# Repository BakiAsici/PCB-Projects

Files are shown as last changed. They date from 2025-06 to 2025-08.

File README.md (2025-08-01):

<h2>ESP32-S3-WROOM-1 V1.1 — Custom PCB - Baki Asici</h2>

<p>
  <strong>Updated from V1.0 with improved routing, GPIO reassignment, and antenna layout adjustments.</strong>
</p>

<p>
  A custom-designed ESP32-S3 board featuring onboard I²C sensors, GPIO breakout headers, and full custom routing.  
  Designed in KiCad 9, fabricated by JLCPCB, and hand-assembled using hot air, hotplate, and soldering iron.
</p>

<h3>Overview</h3>

<ul>
  <li>Revision: Rev 1.1</li>
  <li>Designed in: KiCad 9</li>
  <li>Fabricated by: JLCPCB</li>
  <li>Assembly: Hand soldered (Hotplate, Hot Air, Soldering Iron)</li>
</ul>

<h3>Features</h3>

<ul>
  <li>ESP32-S3-WROOM-1 Module</li>
  <li>I²C-connected STMicroelectronics LIS2MDL magnetometer and Bosch Sensortec BME280 environmental sensor (Temperature, Humidity, Pressure)</li>
  <li>GPIO header breakout</li>
  <li>USB Programming and Monitoring</li>
  <li>WiFi and Bluetooth Capabilities</li>
</ul>

<h3>Noted Improvements from Rev 1.0</h3>
<ul>
  <li>Removed top mounting points to improve WiFi and Bluetooth performance, as recommended by the ESP32-S3-WROOM-1 datasheet</li>
  <li>Test LED (marked D1) was originally wired to a strapping pin (GPIO45), which caused unpredictable behaviour. It has now been rewired to a different GPIO</li>
  <li>Completed Custom Bosch BME280 I2C driver in the esp-idf framework. Reading from registers and applying Boch's calibration code</li>
  <li>Improved overall routing</li>
  <li>Followed ESP32-S3-WROOM-1 datasheet more closely regarding antenna clearance and placement</li>
</ul>
<p>It should be noted that IO numbering on back side of pcb may not fully correspond to what the actual pins are. Check schematic.</p>
<h3>Images</h3>
<div>
PCB 3D Renders
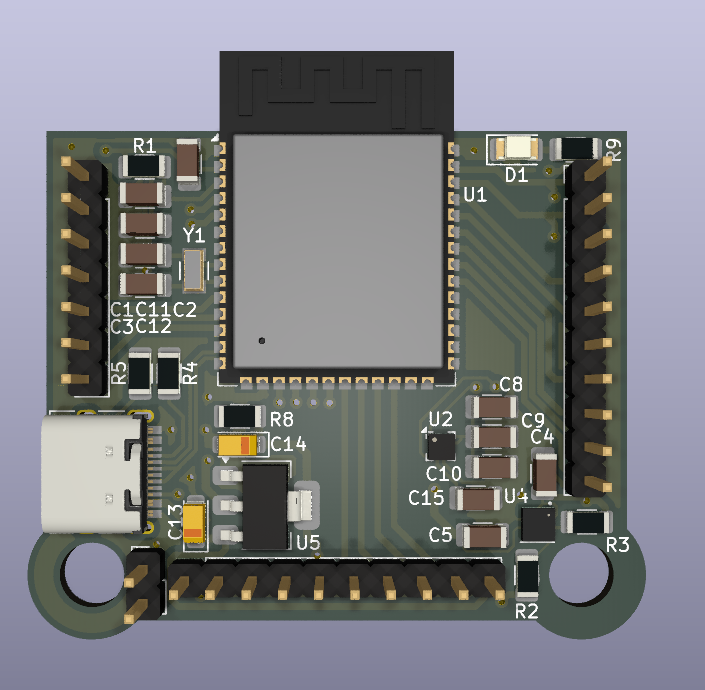
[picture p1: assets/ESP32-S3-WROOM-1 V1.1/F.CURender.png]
Front Render

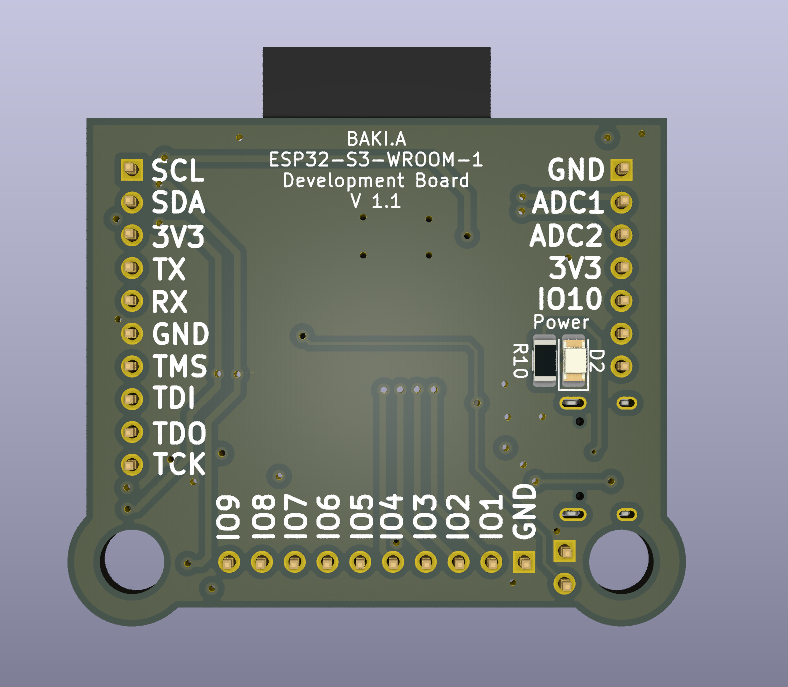
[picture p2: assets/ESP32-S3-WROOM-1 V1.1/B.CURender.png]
Back Render


PCB Photos
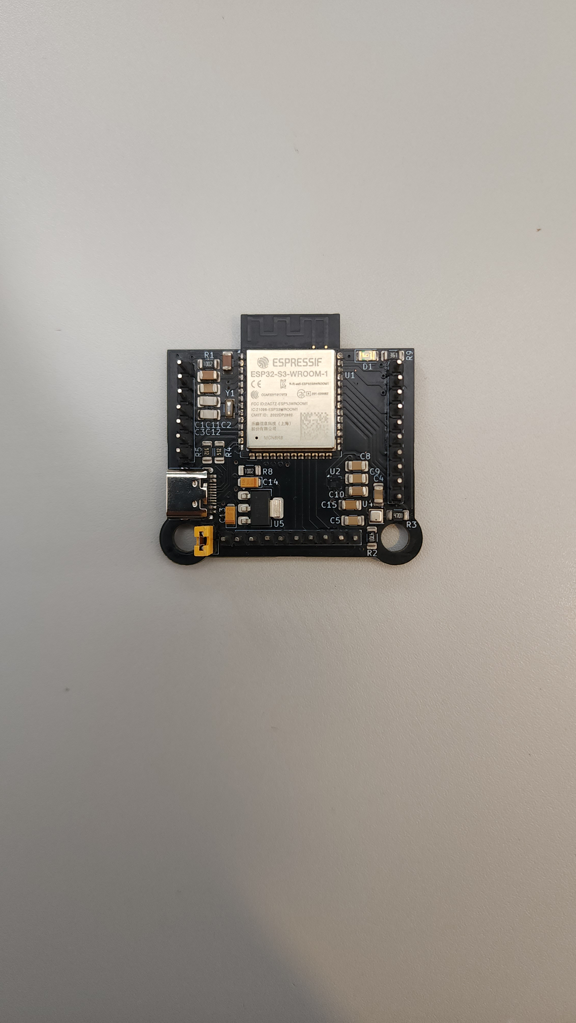
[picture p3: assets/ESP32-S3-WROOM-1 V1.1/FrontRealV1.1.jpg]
Front

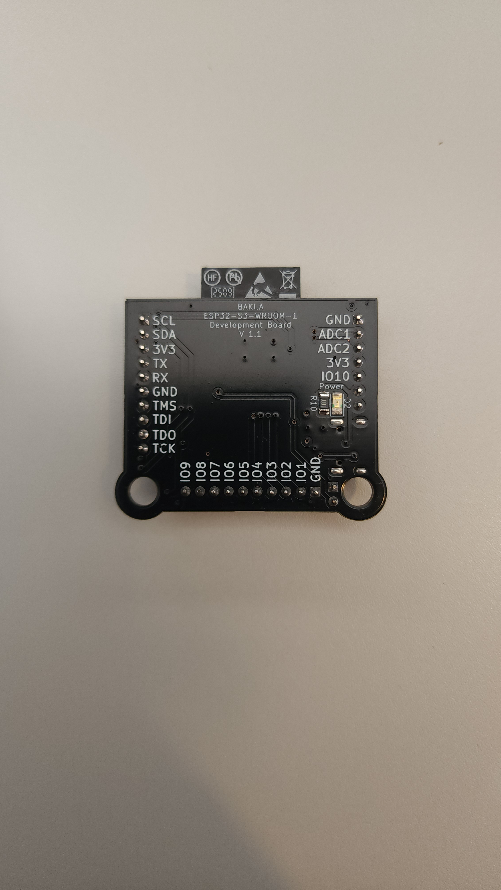
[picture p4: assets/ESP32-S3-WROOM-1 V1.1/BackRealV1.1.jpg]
Back


Layer Stackup
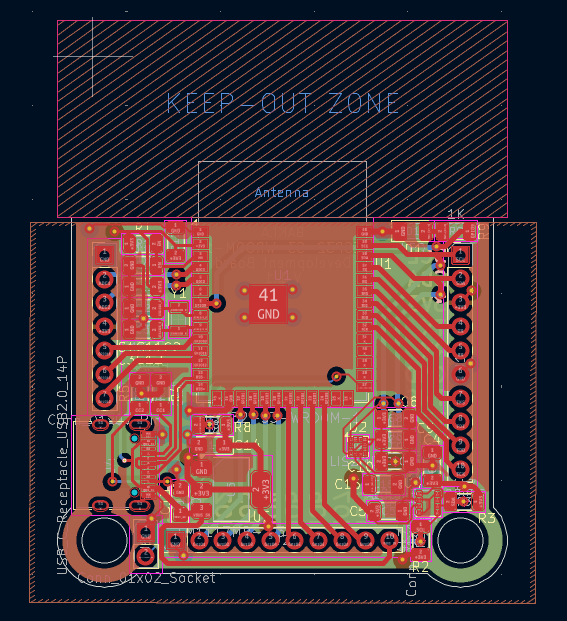
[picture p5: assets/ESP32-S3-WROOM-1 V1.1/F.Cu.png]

F.Cu (Front Copper)	
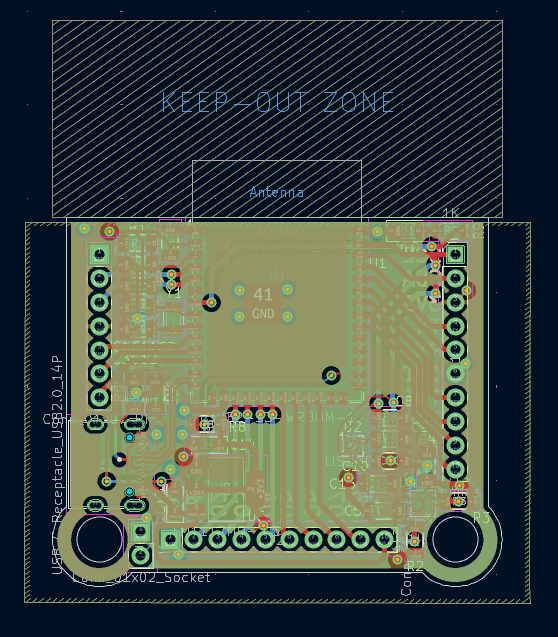
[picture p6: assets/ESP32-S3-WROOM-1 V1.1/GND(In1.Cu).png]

In1.Cu (GND)	
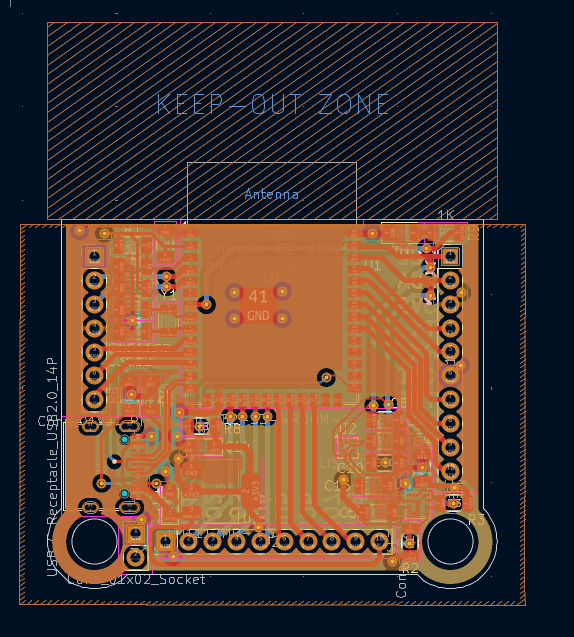
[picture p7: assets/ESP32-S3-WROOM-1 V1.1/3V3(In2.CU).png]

In2.Cu (3V3)	
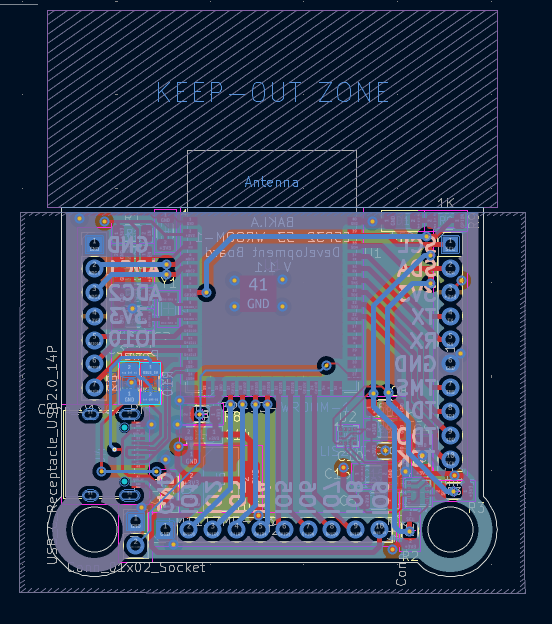
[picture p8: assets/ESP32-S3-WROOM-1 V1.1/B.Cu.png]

B.Cu (Back Copper)

<h2>ESP32-S3-WROOM-1 V1.0 — Custom PCB</h2>

<p>
  A custom-designed ESP32-S3 board featuring onboard I²C sensors, GPIO breakout headers, and full custom routing.  
  Designed in KiCad 9, fabricated by JLCPCB, and hand-assembled using hot air, hotplate, and soldering iron.
</p>

<h3>Overview</h3>

  <ul>
  <li>Revision: Rev 1.0</li>
  <li>Designed in: KiCad 9</li>
  <li>Fabricated by: JLCPCB</li>
  <li>Assembly: Hand soldered (Hotplate, Hot Air, Soldering Iron)</li>
</ul>

<h3>Features</h3>

<ul>
  <li>ESP32-S3-WROOM-1 Module</li>
  <li>I²C-connected STMicroelectronics LIS2MDL magnetometer and Bosch Sensortec BME280 environmental sensor(Temperature, Humidity, Pressure)</li>
  <li>Sensor libraries used to test functionality with custom drivers in the works</li>
  <li>GPIO header breakout</li>
  <li>USB Programming and Monitoring</li>
  <li>Wifi and Bluetooth Capabilities</li>
</ul>

<h3>Noted Improvements for next revision</h3>
<ul>
  <li>Remove top mounting points to increase Wifi and Bluetooth performance, as recommemnded by the ESP32-S3-WROOM-1 datasheet</li>
  <li>Test led (Marked D1) was wired using a strapping pin GPIO45 and had to be left of the board to ensure predictable behaviour. Rewire led to a new GPIO</li>
  <li>Improve overall routing</li>
  <li>It should be noted that the current limiting resstor for the power indicator led was changed to 180ohms. I am unsure if it will work with the original 1Kohm</li>
</ul>

<h3>Images</h3>
<div >
PCB 3D Renders
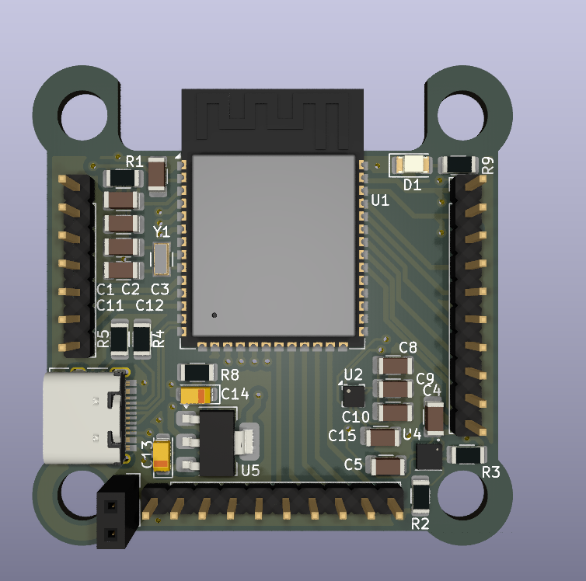
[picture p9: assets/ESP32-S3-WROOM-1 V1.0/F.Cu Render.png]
Front Render

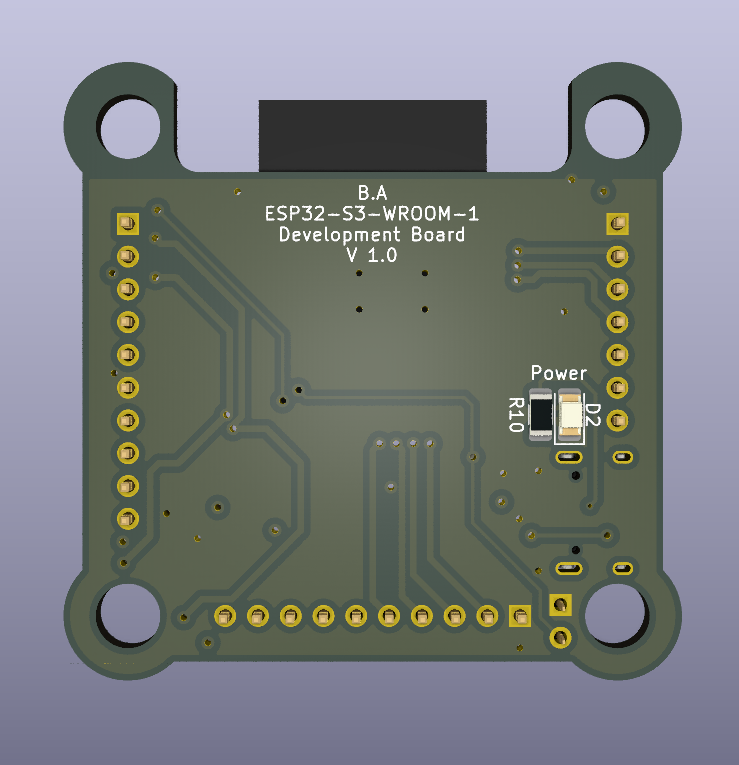
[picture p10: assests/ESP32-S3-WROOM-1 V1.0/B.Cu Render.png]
Back Render


PCB Photos
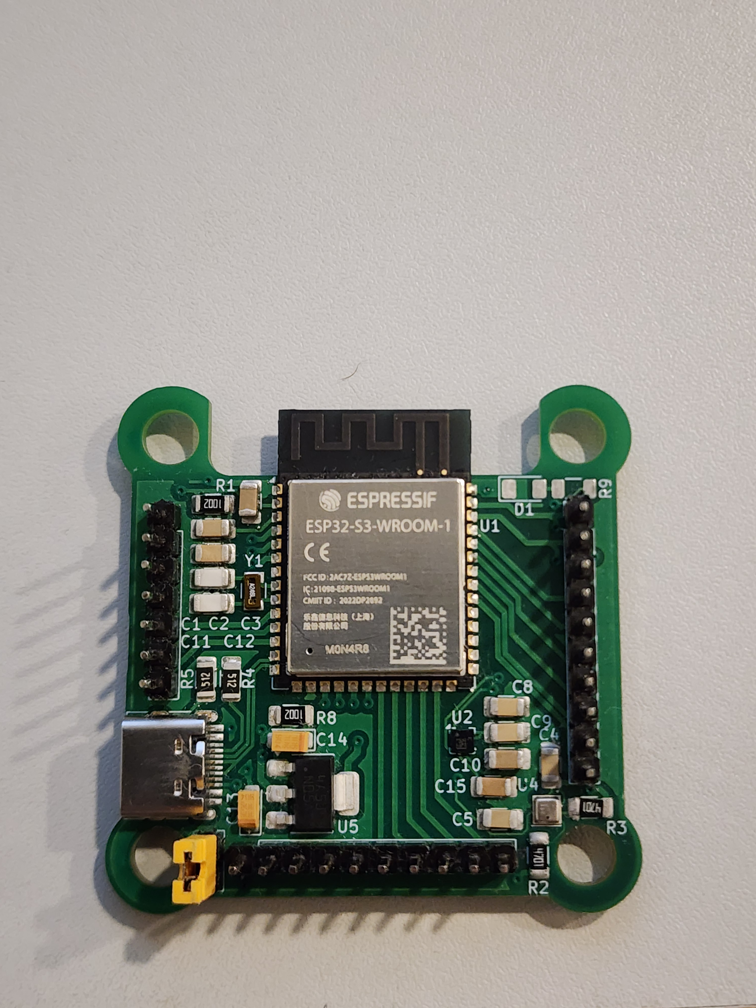
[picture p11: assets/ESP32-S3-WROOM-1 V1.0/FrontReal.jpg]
Front

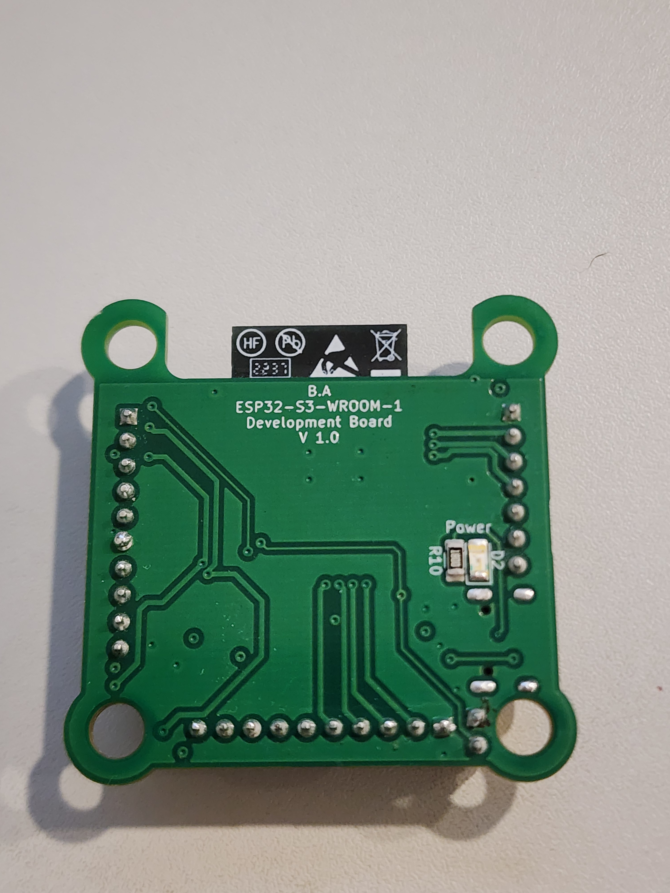
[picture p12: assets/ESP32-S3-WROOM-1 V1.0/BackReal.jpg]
Back


Layer Stackup
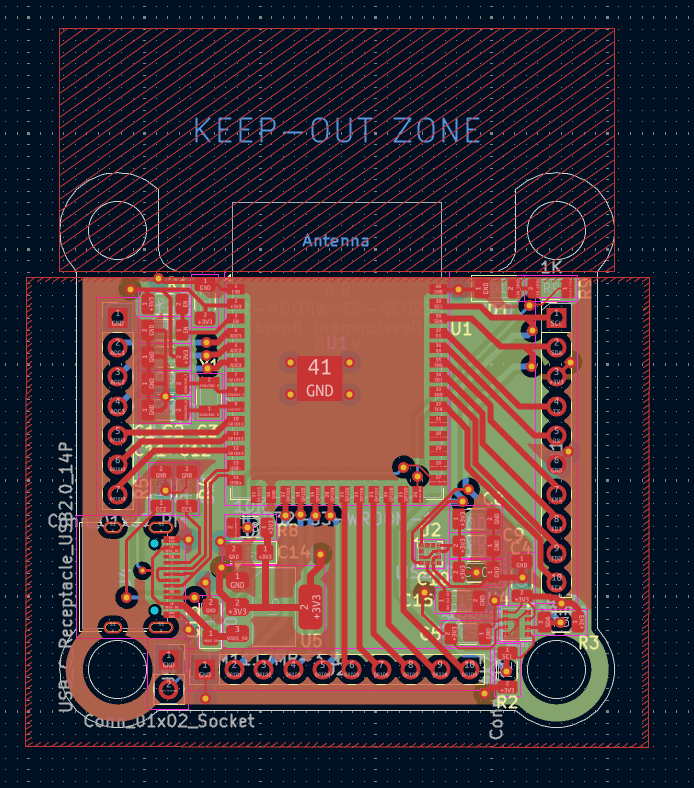
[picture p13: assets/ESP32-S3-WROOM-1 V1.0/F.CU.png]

F.Cu (Front Copper)	
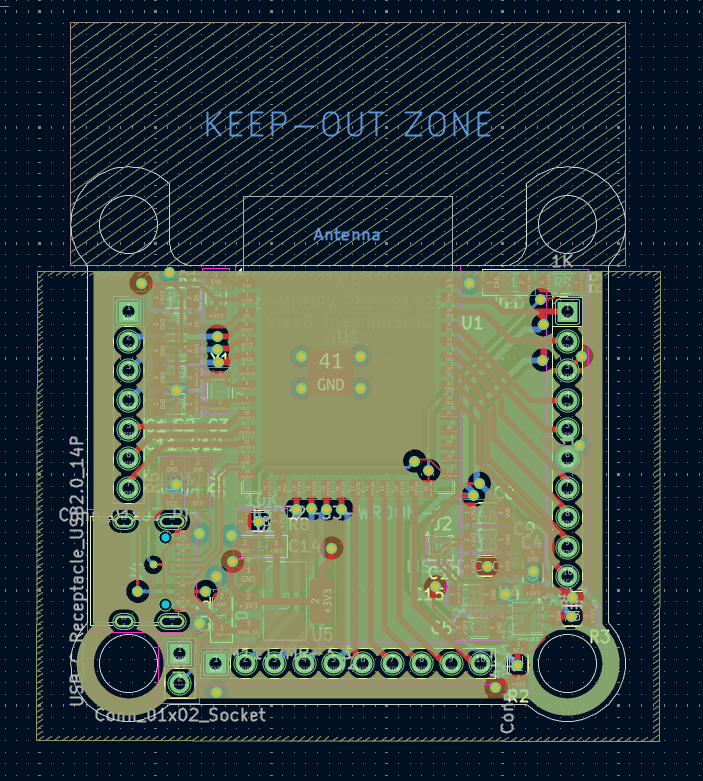
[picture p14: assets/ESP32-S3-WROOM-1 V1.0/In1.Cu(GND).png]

In1.Cu (GND)	
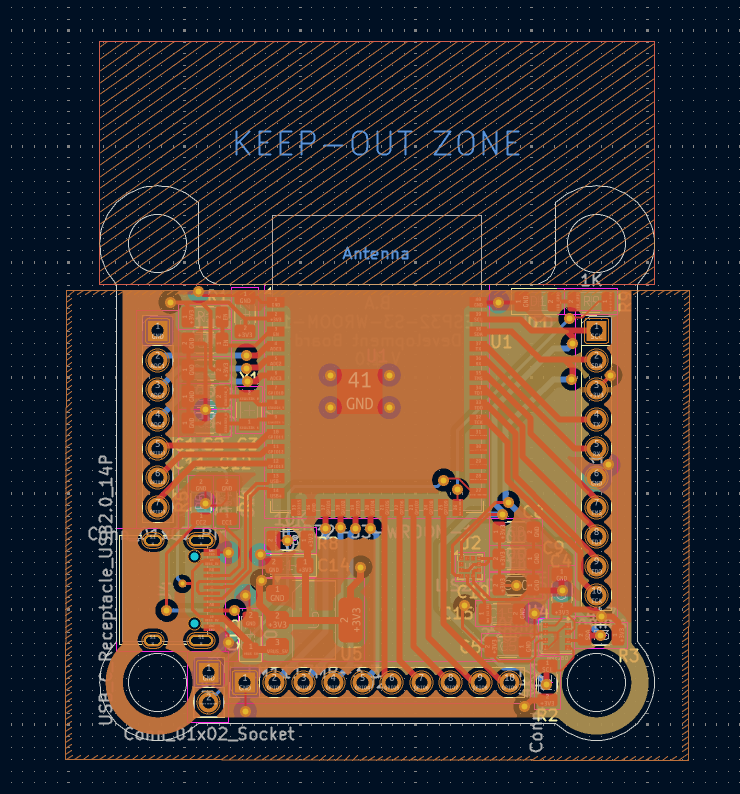
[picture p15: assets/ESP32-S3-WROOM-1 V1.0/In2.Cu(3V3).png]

In2.Cu (3V3)	
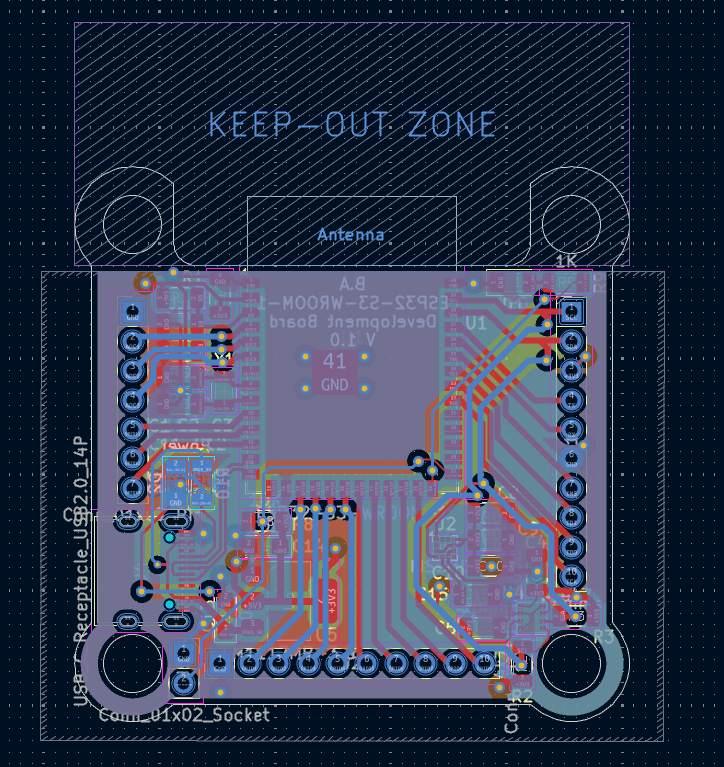
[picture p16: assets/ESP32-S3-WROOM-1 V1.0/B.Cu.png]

B.Cu (Back Copper)

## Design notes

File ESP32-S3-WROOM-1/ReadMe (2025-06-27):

This is a ESP32-S3 based embedded prototyping and iot pcb I have made custom. I desgined it in Kicad 9 and manufactured it with JLCPCB. All Schematics and PCB files for each revisions are listed here

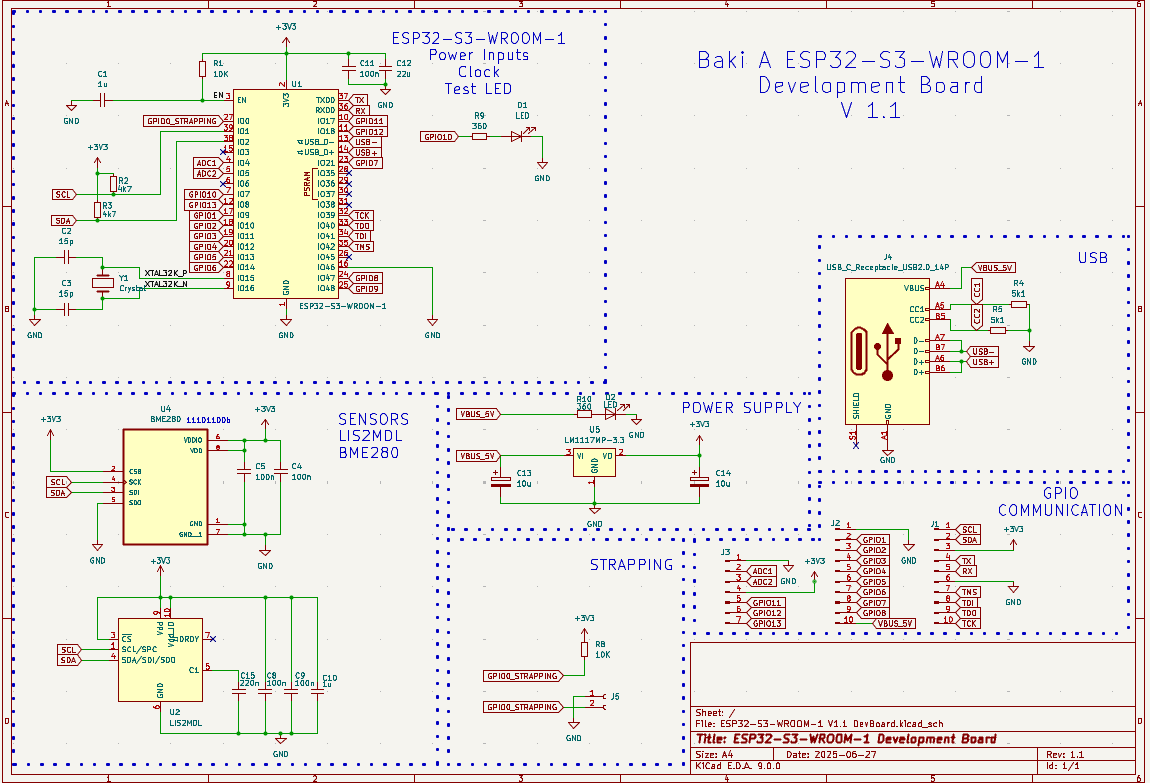
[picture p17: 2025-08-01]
ESP32-S3-WROOM-1/Rev-1.1/Schematic.png

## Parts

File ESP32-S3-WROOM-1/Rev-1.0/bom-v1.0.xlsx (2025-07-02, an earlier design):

Reference | Qty | Value | Footprint
C1,C10 | 2 | 1u | Capacitor_SMD:C_1206_3216Metric
C2,C3 | 2 | 15p | Capacitor_SMD:C_1206_3216Metric
C4,C5,C8,C9,C11 | 5 | 100n | Capacitor_SMD:C_1206_3216Metric
C12 | 1 | 22u | Capacitor_SMD:C_1206_3216Metric
C13,C14 | 2 | 10u | Capacitor_Tantalum_SMD:CP_EIA-3216-18_Kemet-A
C15 | 1 | 220n | Capacitor_SMD:C_1206_3216Metric
D1,D2 | 2 | LED | LED_SMD:LED_1206_3216Metric
J1 | 1 | Comms | Connector_PinHeader_2.54mm:PinHeader_1x10_P2.54mm_Vertical
J2 | 1 | Conn_01x10_Pin | Connector_PinHeader_2.54mm:PinHeader_1x10_P2.54mm_Vertical
J3 | 1 | Conn_01x07_Pin | Connector_PinHeader_2.54mm:PinHeader_1x07_P2.54mm_Vertical
J4 | 1 | USB_C_Receptacle_USB2.0_14P | Connector_USB:USB_C_Receptacle_HRO_TYPE-C-31-M-12
J5 | 1 | Conn_01x02_Socket | Connector_PinSocket_2.54mm:PinSocket_1x02_P2.54mm_Vertical
R1,R8 | 2 | 10K | Resistor_SMD:R_1206_3216Metric
R2,R3 | 2 | 4k7 | Resistor_SMD:R_1206_3216Metric
R4,R5 | 2 | 5k1 | Resistor_SMD:R_1206_3216Metric
R9,R10 | 2 | 1K | Resistor_SMD:R_1206_3216Metric
U1 | 1 | ESP32-S3-WROOM-1 | RF_Module:ESP32-S3-WROOM-1
U2 | 1 | LIS2MDL | Package_LGA:LGA-12_2x2mm_P0.5mm
U4 | 1 | BME280 | BME280:PSON65P250X250X100-8N
U5 | 1 | LM1117MP-3.3 | Package_TO_SOT_SMD:SOT-223-3_TabPin2
Y1 | 1 | Crystal | Crystal:Crystal_SMD_3215-2Pin_3.2x1.5mm

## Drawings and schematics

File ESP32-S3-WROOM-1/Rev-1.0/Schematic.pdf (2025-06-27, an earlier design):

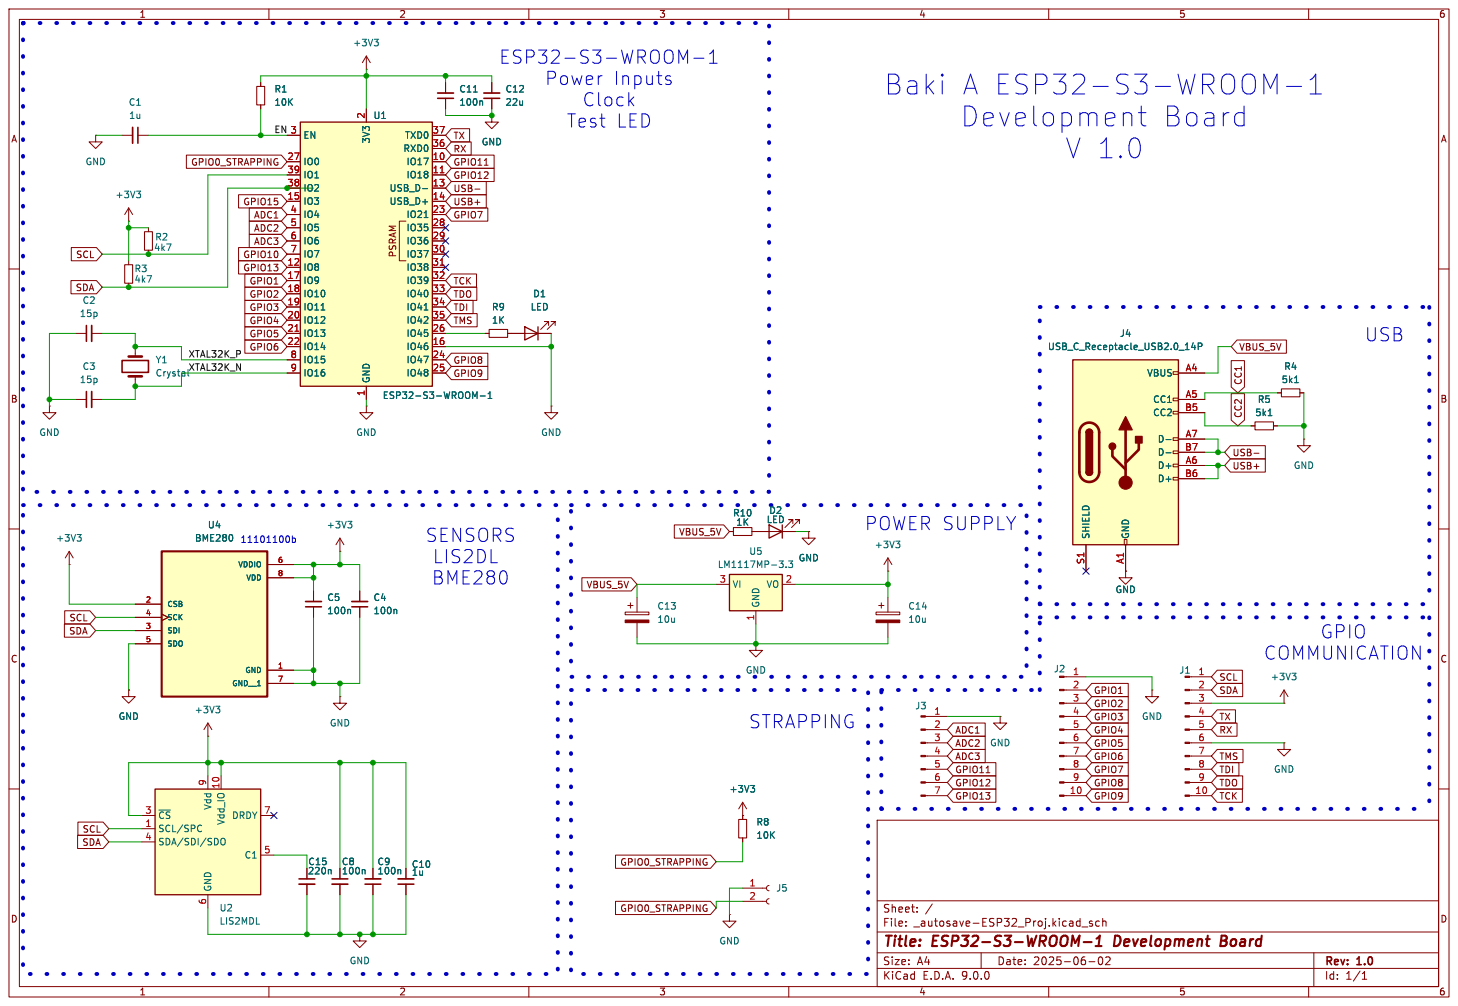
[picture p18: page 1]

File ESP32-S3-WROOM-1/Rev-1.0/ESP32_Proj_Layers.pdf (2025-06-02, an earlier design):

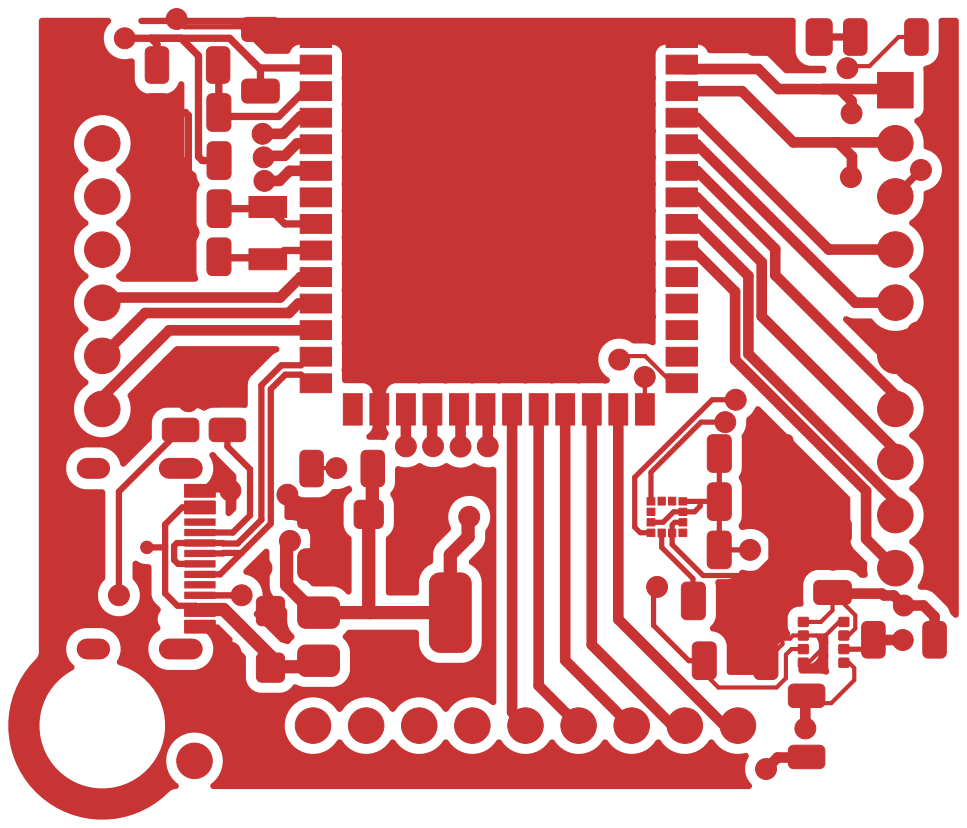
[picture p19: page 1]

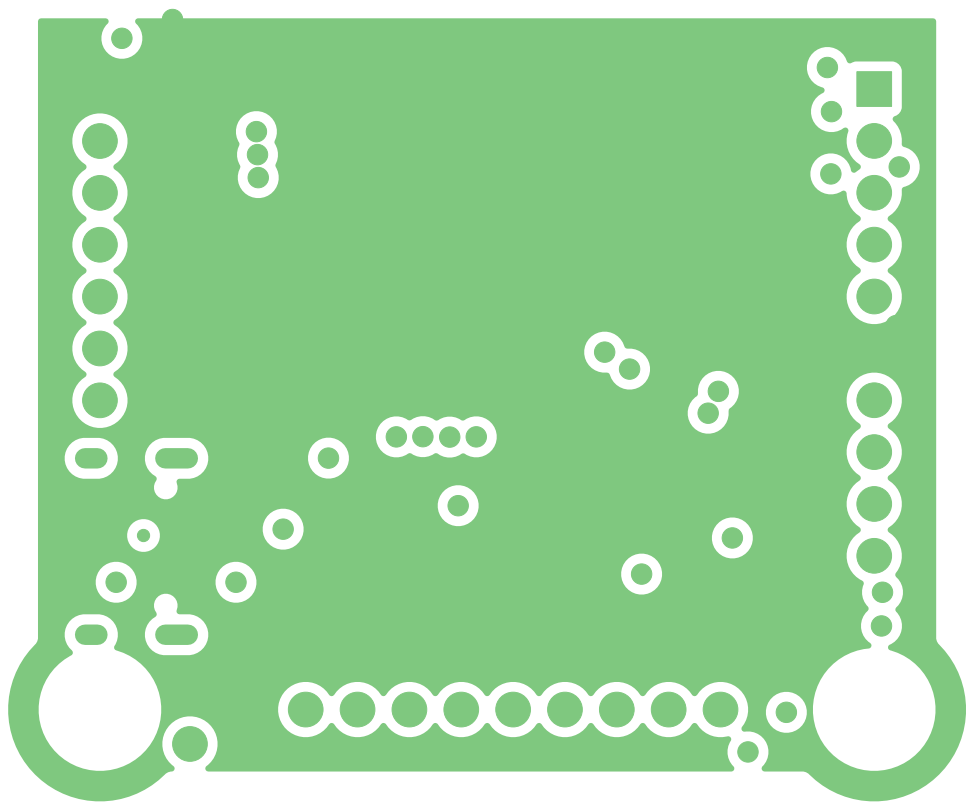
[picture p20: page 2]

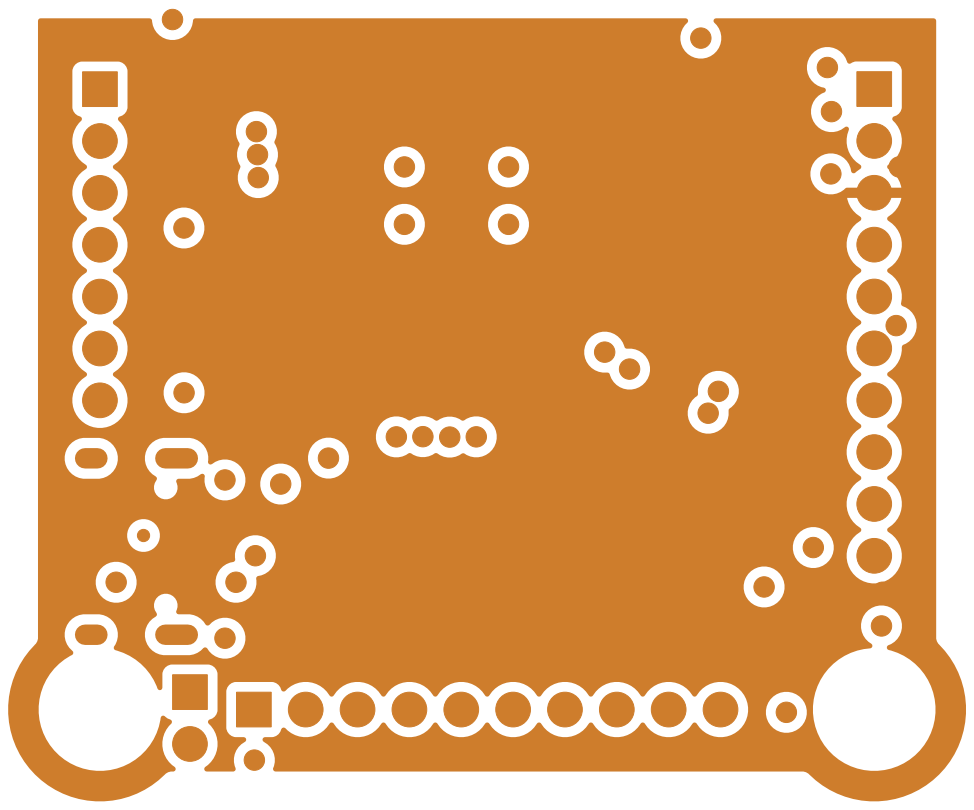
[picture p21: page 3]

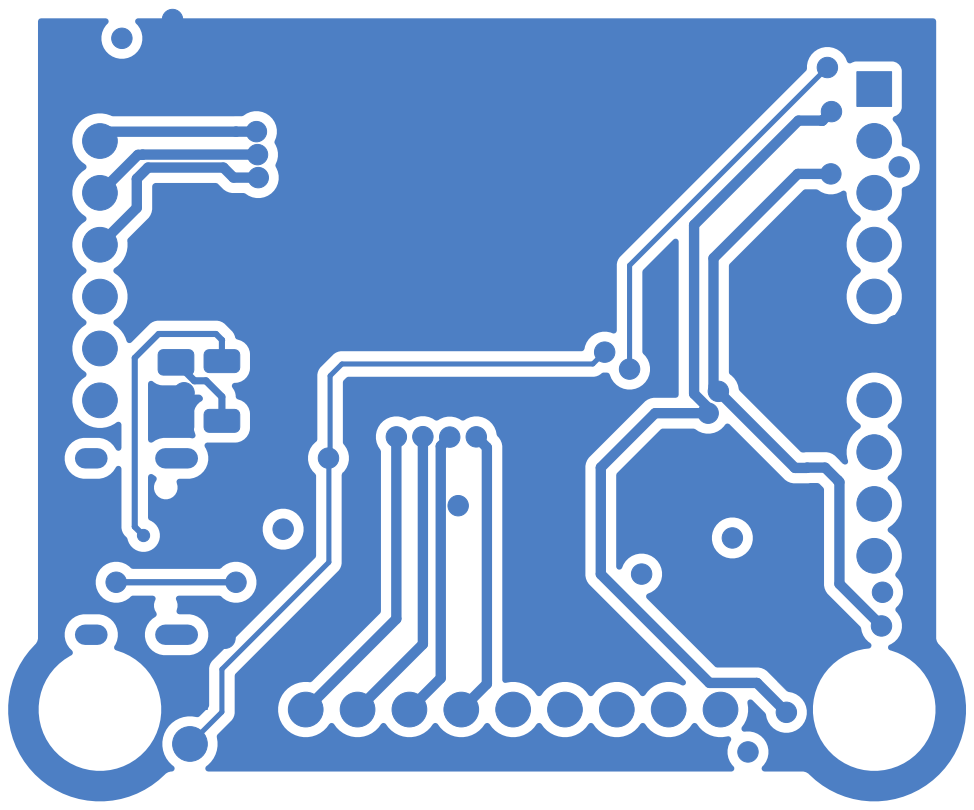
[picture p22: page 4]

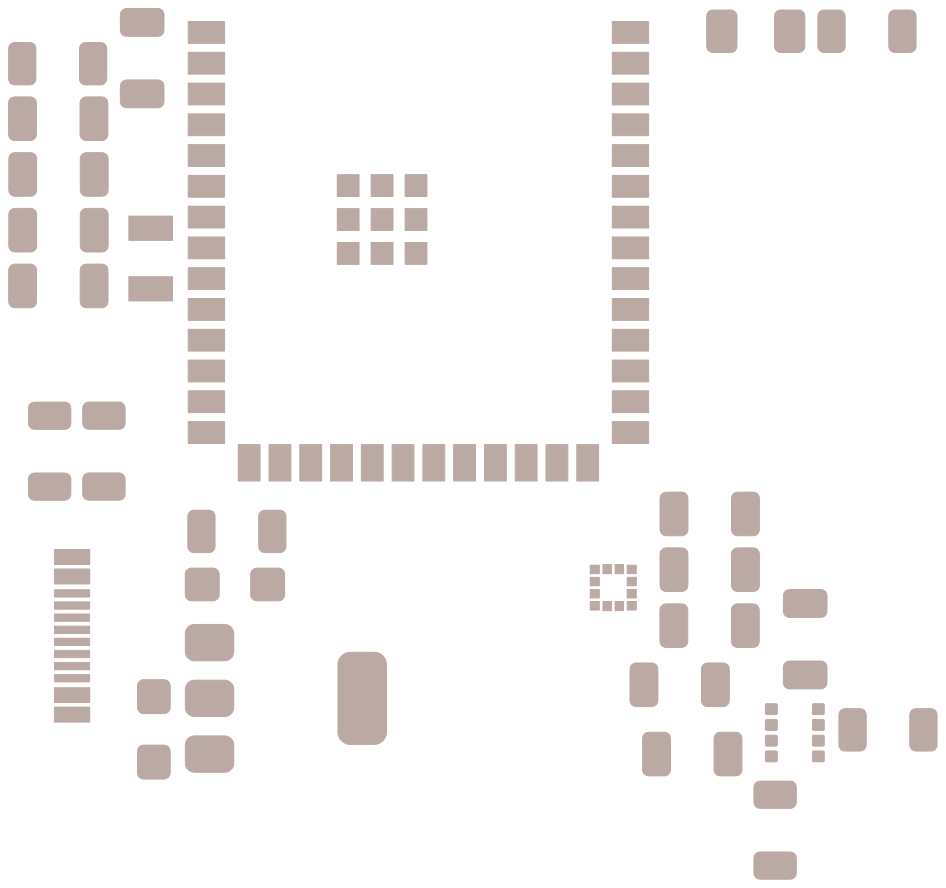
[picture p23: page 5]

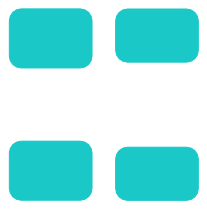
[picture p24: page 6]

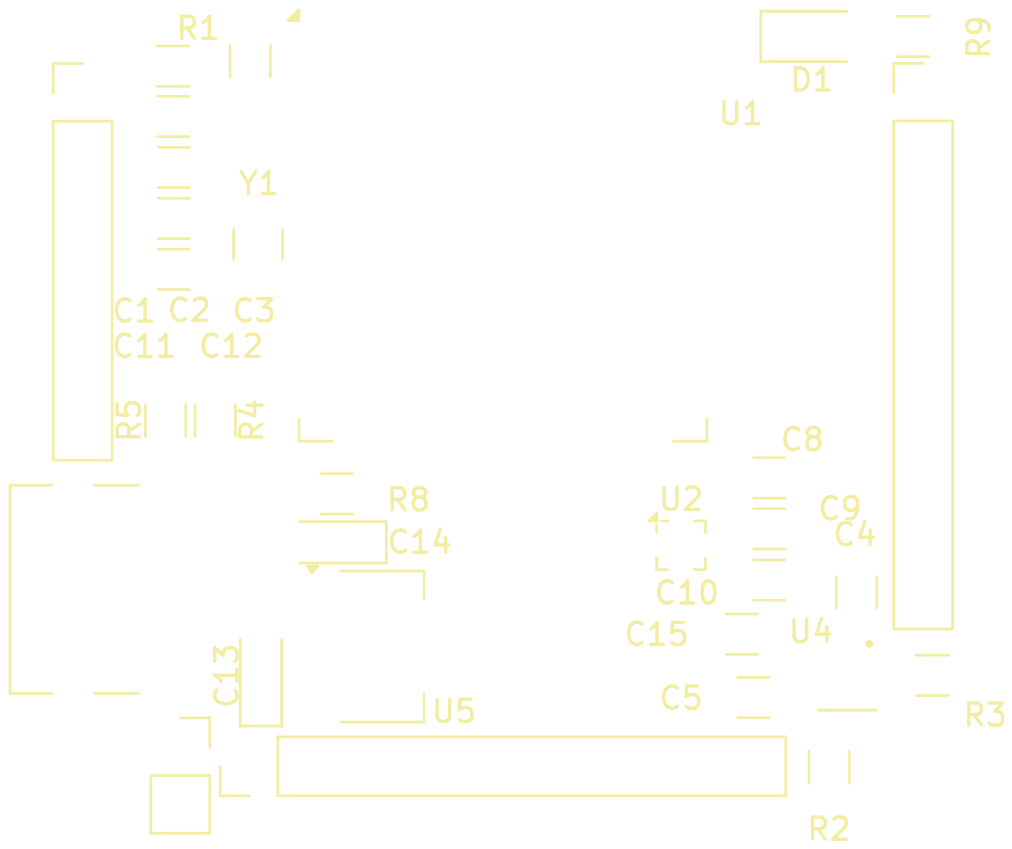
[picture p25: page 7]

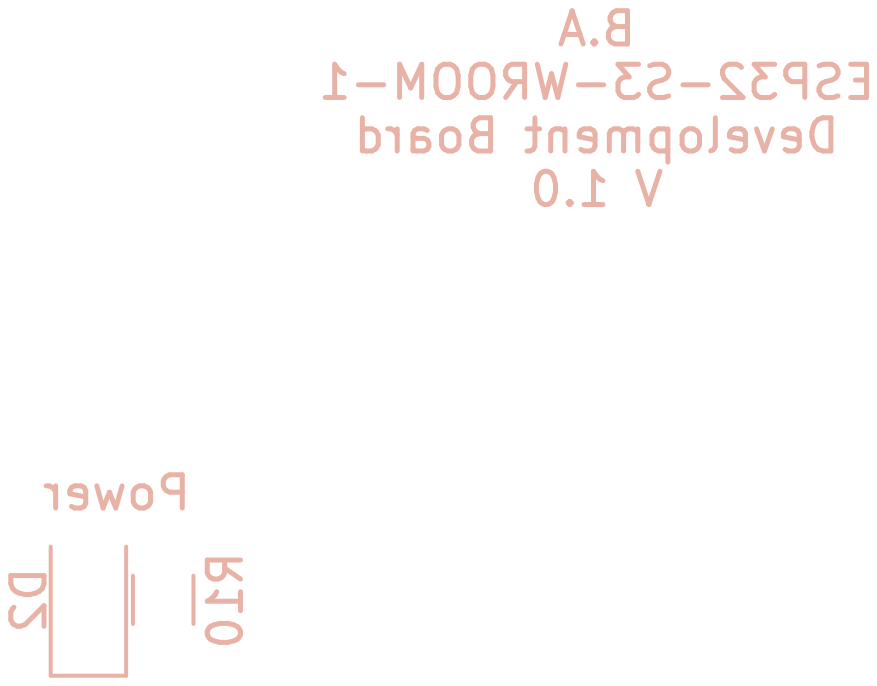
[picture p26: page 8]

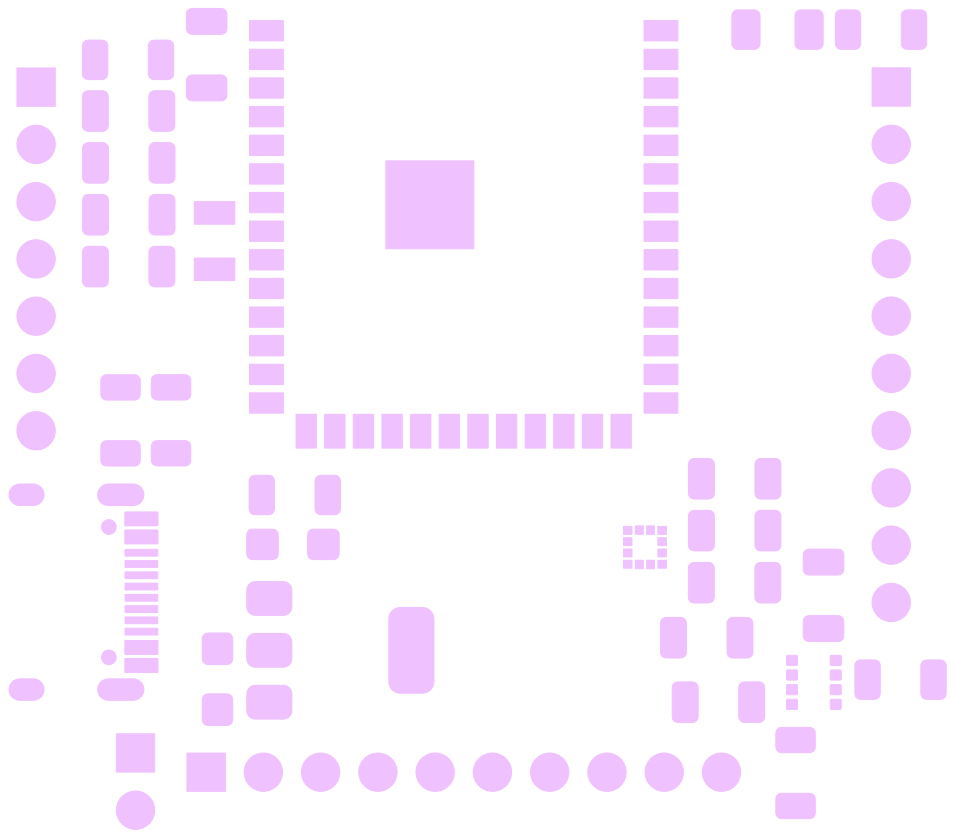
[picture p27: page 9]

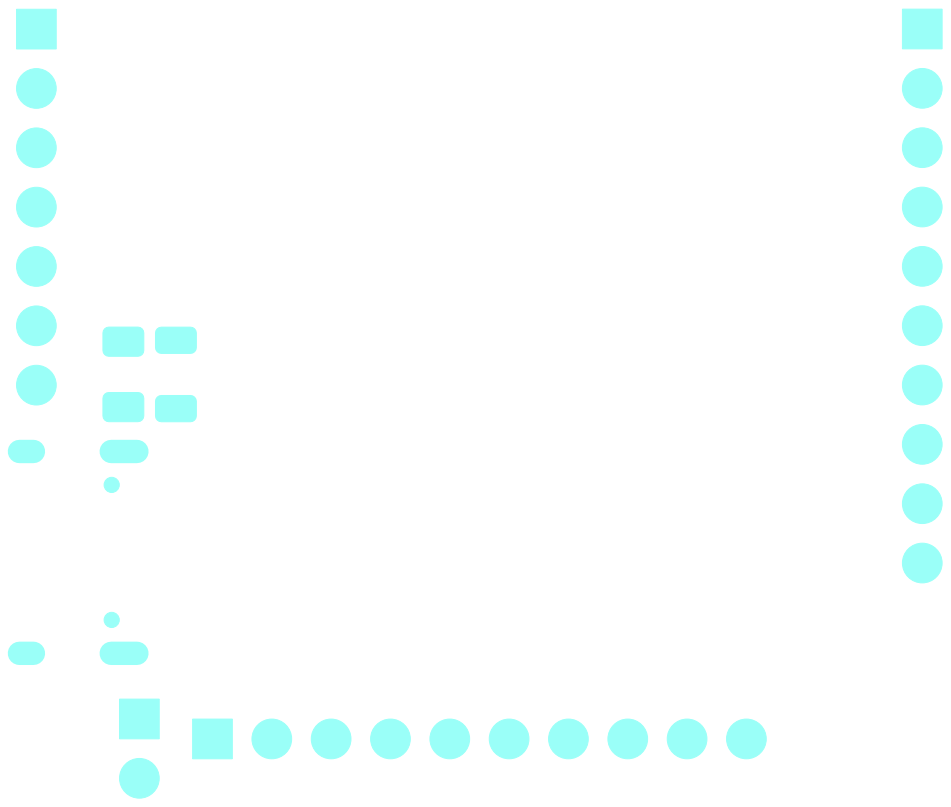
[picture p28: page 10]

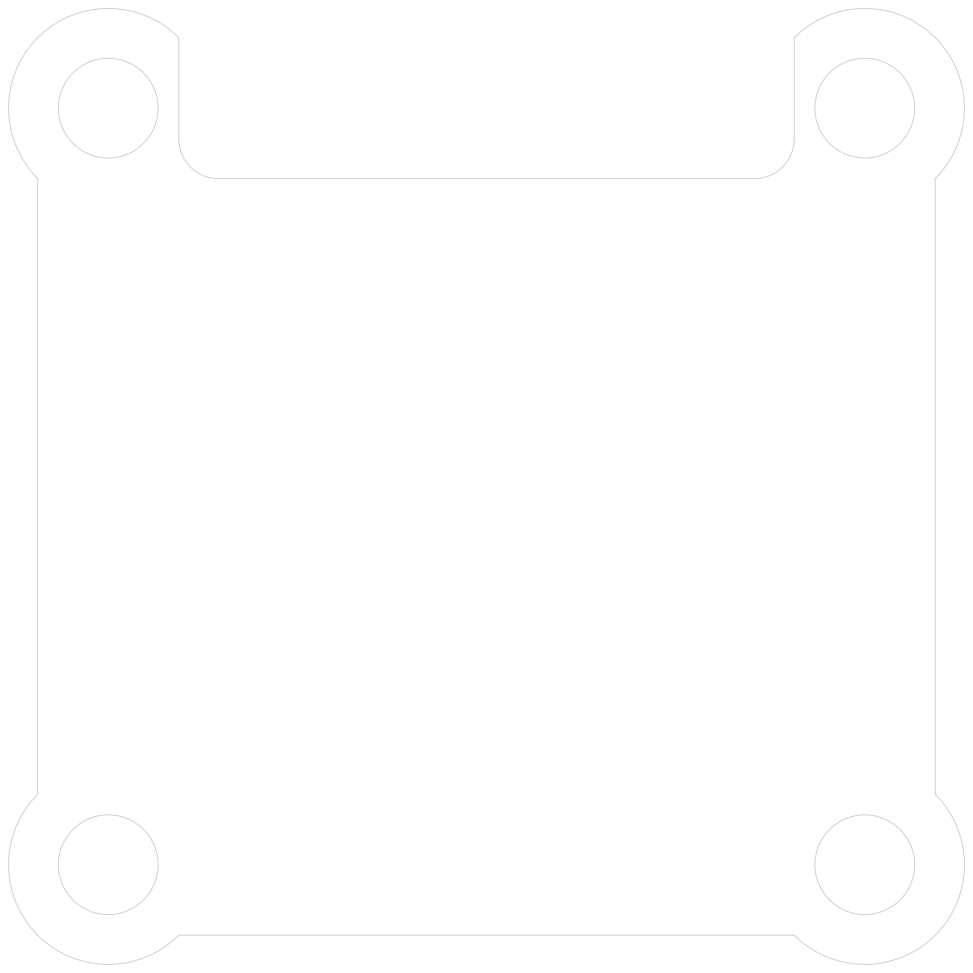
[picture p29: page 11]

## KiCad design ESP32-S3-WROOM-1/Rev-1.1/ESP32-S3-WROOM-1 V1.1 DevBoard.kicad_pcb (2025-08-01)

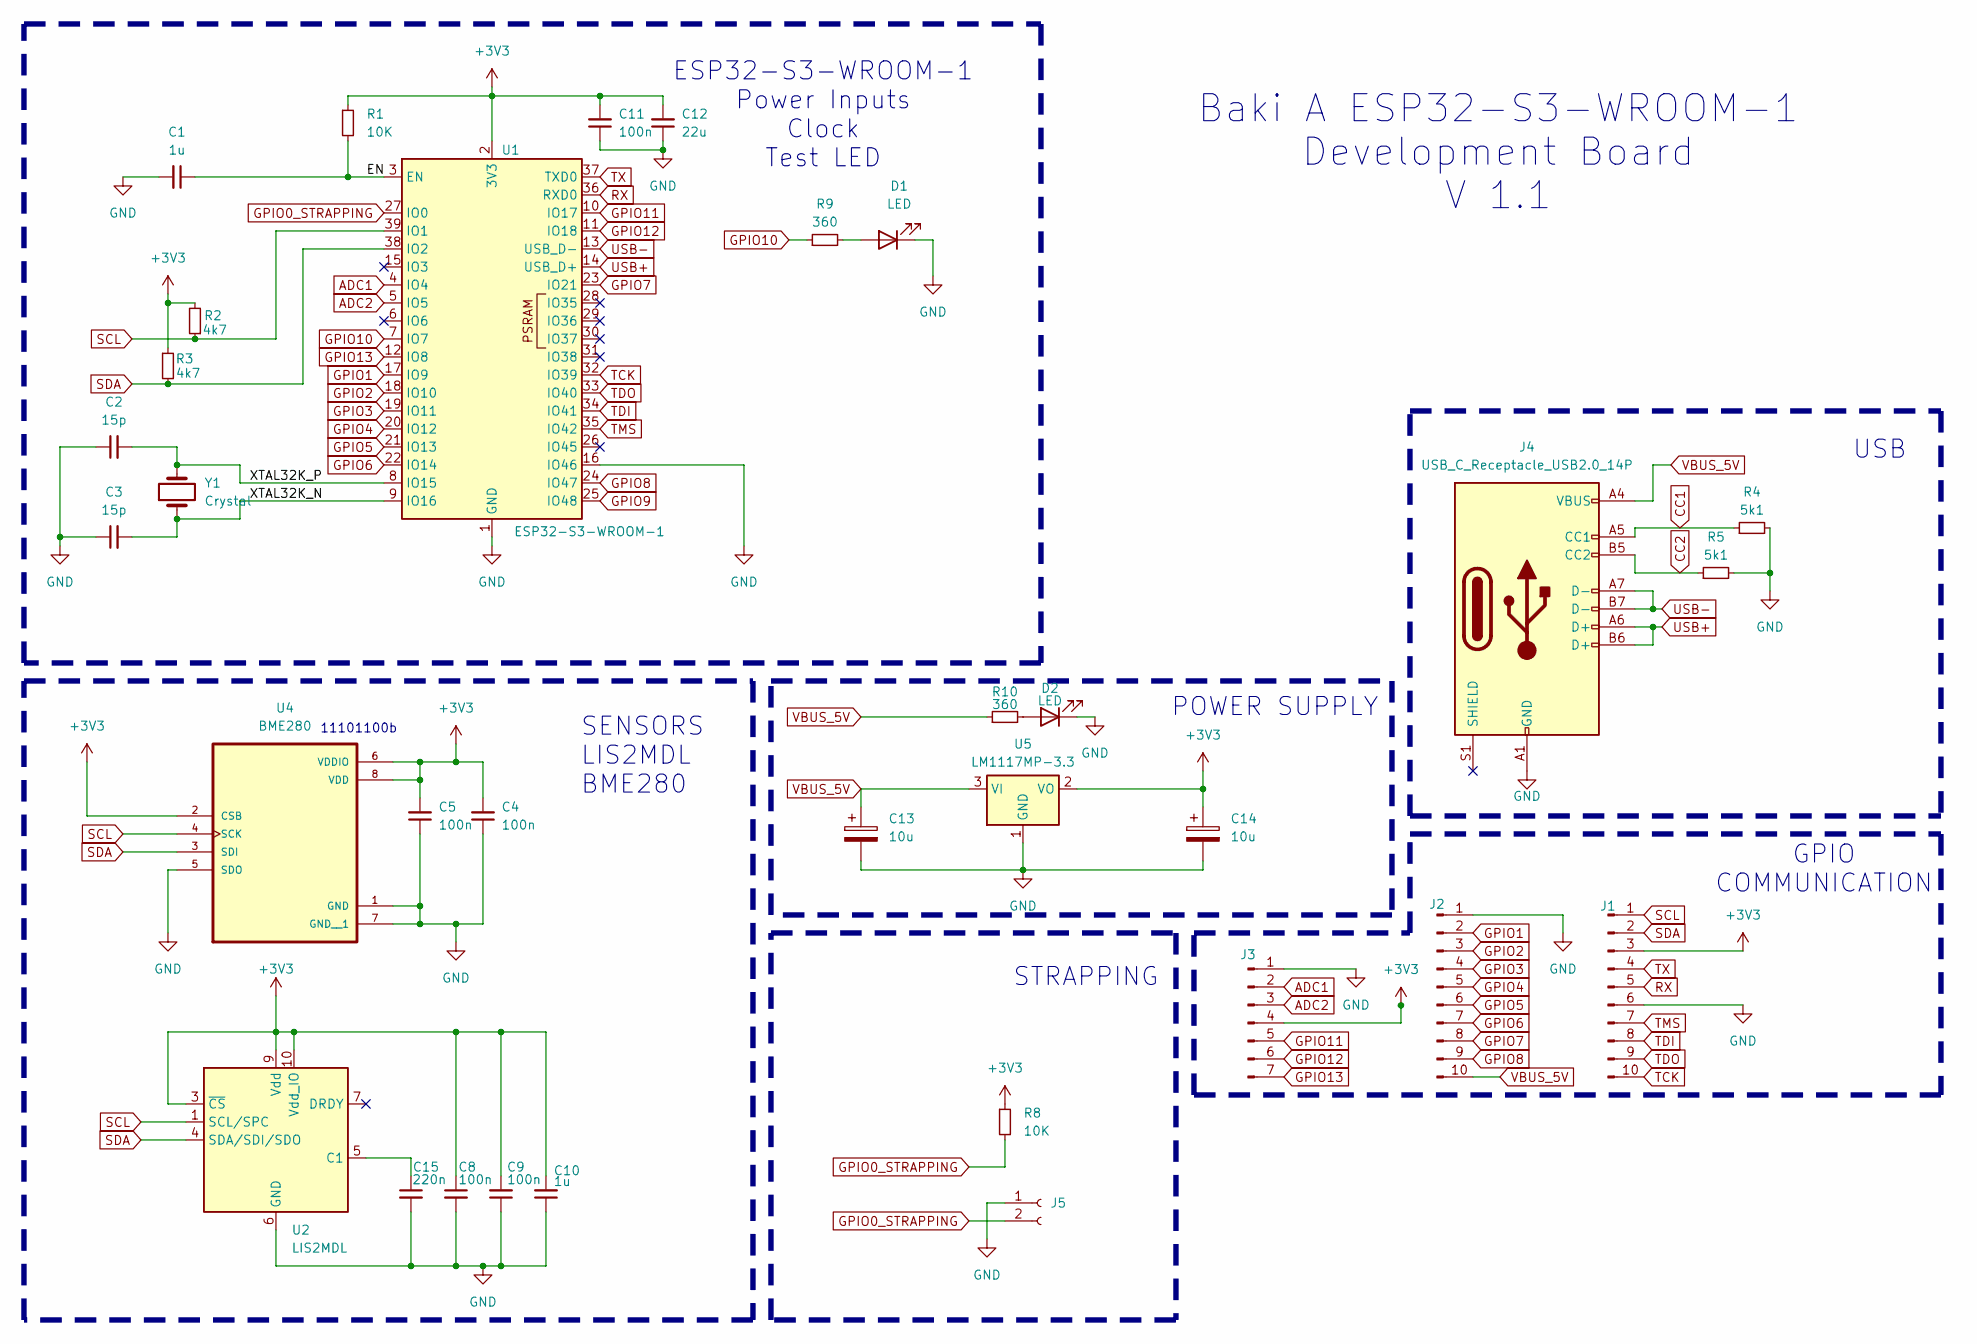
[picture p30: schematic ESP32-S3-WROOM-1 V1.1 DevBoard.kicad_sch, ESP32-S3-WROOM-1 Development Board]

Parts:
C1, C10: 1u; C_1206_3216Metric
C2, C3: 15p; C_1206_3216Metric
C4, C5, C8, C9, C11: 100n; C_1206_3216Metric
C12: 22u; C_1206_3216Metric
C13, C14: 10u; CP_EIA-3216-18_Kemet-A
C15: 220n; C_1206_3216Metric
D1, D2: LED; LED_1206_3216Metric
J1: Comms; PinHeader_1x10_P2.54mm_Vertical
J2: Conn_01x10_Pin; PinHeader_1x10_P2.54mm_Vertical
J3: Conn_01x07_Pin; PinHeader_1x07_P2.54mm_Vertical
J4: USB_C_Receptacle_USB2.0_14P; USB_C_Receptacle_HRO_TYPE-C-31-M-12
J5: Conn_01x02_Socket; PinSocket_1x02_P2.54mm_Vertical
R1, R8: 10K; R_1206_3216Metric
R2, R3: 4k7; R_1206_3216Metric
R4, R5: 5k1; R_1206_3216Metric
R9, R10: 360; R_1206_3216Metric
U1: ESP32-S3-WROOM-1
U2: LIS2MDL; LGA-12_2x2mm_P0.5mm
U4: BME280; PSON65P250X250X100-8N
U5: LM1117MP-3.3; SOT-223-3_TabPin2
Y1: Crystal; Crystal_SMD_3215-2Pin_3.2x1.5mm

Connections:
+3V3: C4.2, C5.2, C8.1, C9.2, C10.2, C11.2, C12.2, C14.1, J1.3, J3.4, R1.1, R2.2, R3.1, R8.1, U1.2 (3V3), U2.3 (~CS), U2.9 (Vdd), U2.10 (Vdd_IO), U4.2 (CSB), U4.6 (VDDIO), U4.8 (VDD), U5.2 (VO)
/EN: C1.1, R1.2, U1.3 (EN)
/XTAL32K_N: C3.2, U1.9 (IO16), Y1.1
/XTAL32K_P: C2.2, U1.8 (IO15), Y1.2
ADC1: J3.2, U1.4 (IO4)
ADC2: J3.3, U1.5 (IO5)
CC1: J4.A5 (CC1), R4.1
CC2: J4.B5 (CC2), R5.1
GND: C1.2, C2.1, C3.1, C4.1, C5.1, C8.2, C9.1, C10.1, C11.1, C12.1, C13.2, C14.2, C15.2, D1.1 (K), D2.1 (K), J1.6, J2.1, J3.1, J4.A1 (GND), J4.A12 (GND), J4.B1 (GND), J4.B12 (GND), J5.1, R4.2, R5.2, U1.1 (GND), U1.16 (IO46), U1.40 (GND), U1.41 (GND), U2.6 (GND), U2.8 (GND), U4.1 (GND), U4.5 (SDO), U4.7 (GND__1), U5.1 (GND)
GPIO0_STRAPPING: J5.2, R8.2, U1.27 (IO0)
GPIO1: J2.2, U1.17 (IO9)
GPIO2: J2.3, U1.18 (IO10)
GPIO3: J2.4, U1.19 (IO11)
GPIO4: J2.5, U1.20 (IO12)
GPIO5: J2.6, U1.21 (IO13)
GPIO6: J2.7, U1.22 (IO14)
GPIO7: J2.8, U1.23 (IO21)
GPIO8: J2.9, U1.24 (IO47)
GPIO9: R9.1, U1.7 (IO7)
GPIO10: J3.5, U1.10 (IO17)
GPIO11: J3.6, U1.11 (IO18)
GPIO12: J3.7, U1.12 (IO8)
unnamed: D1.2 (A), R9.2
unnamed: D2.2 (A), R10.2
unnamed: C15.1, U2.5 (C1)
RX: J1.5, U1.36 (RXD0)
SCL: J1.1, R2.1, U1.39 (IO1), U2.1 (SCL/SPC), U4.4 (SCK)
SDA: J1.2, R3.2, U1.38 (IO2), U2.4 (SDA/SDI/SDO), U4.3 (SDI)
TCK: J1.10, U1.32 (IO39)
TDI: J1.8, U1.34 (IO41)
TDO: J1.9, U1.33 (IO40)
TMS: J1.7, U1.35 (IO42)
TX: J1.4, U1.37 (TXD0)
USB+: J4.A6 (D+), J4.B6 (D+), U1.14 (USB_D+)
USB-: J4.A7 (D-), J4.B7 (D-), U1.13 (USB_D-)
VBUS_5V: C13.1, J2.10, J4.A4 (VBUS), J4.A9 (VBUS), J4.B4 (VBUS), J4.B9 (VBUS), R10.1, U5.3 (VI)

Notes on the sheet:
Baki A ESP32-S3-WROOM-1 Development Board V 1.1
USB
11101100b
POWER SUPPLY
GPIO COMMUNICATION
SENSORS LIS2MDL BME280
STRAPPING
ESP32-S3-WROOM-1 Power Inputs Clock Test LED

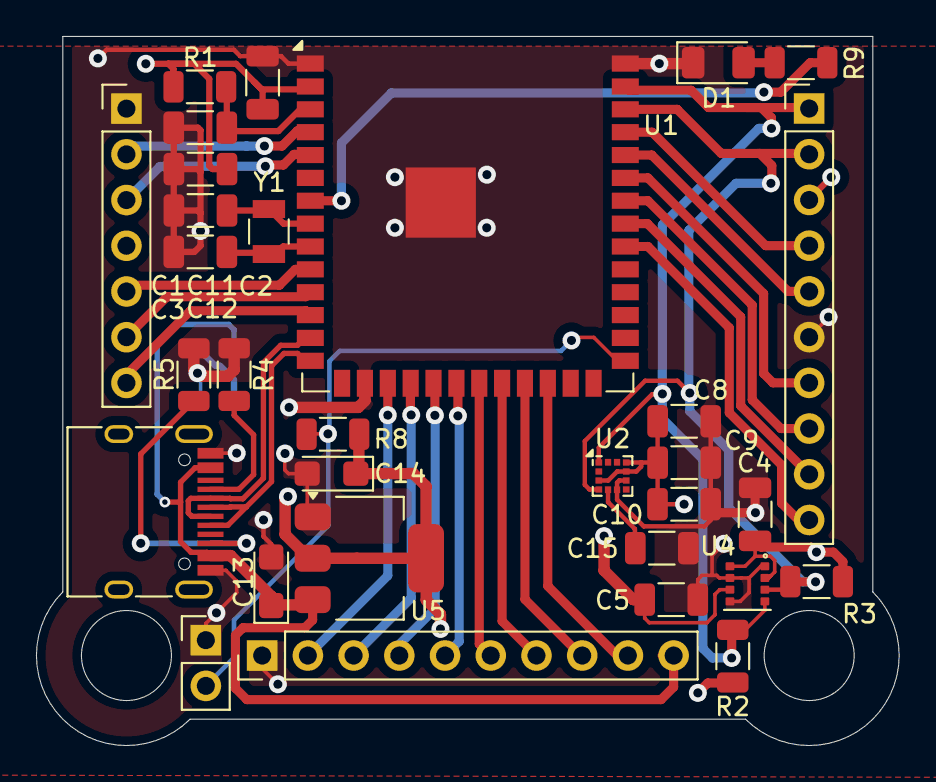
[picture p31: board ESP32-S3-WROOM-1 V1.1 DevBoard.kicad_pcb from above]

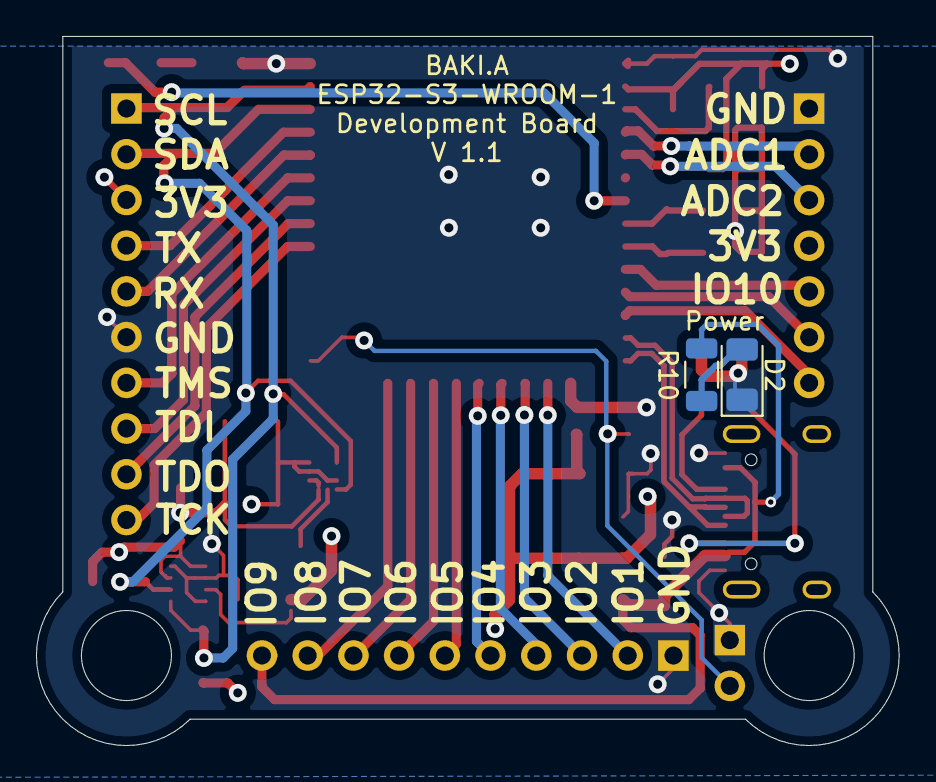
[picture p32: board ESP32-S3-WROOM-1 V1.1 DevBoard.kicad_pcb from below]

Board: 4 copper layers, 47.9 x 39.4 mm, 33 parts (2 on the bottom side), 36 nets.

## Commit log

2025-06-27 Folder name change and general formatting
    [ESP32_Proj.kicad_pcb, ESP32_Proj.kicad_sch]
2025-06-27 new schematic pdf
2025-07-02 added gerber
2025-07-02 added bom
    [bom-v1.0.xlsx]
